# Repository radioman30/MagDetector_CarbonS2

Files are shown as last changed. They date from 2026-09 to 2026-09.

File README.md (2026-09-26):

# MagDetector — Carbon S2

Instrument portabil 4-în-1 pe GroundStudio Carbon S2 (ESP32-S2FN4R2):
**busolă** · **detector poli magnet** · **detector cabluri 50 Hz** · **mini stație meteo**

## Hardware

| Componentă | Conexiune |
|---|---|
| HMC5883L (magnetometru, original Honeywell, 0x1E) | I2C: SDA=GPIO8, SCL=GPIO9 |
| BME280 (temp/umiditate/presiune, 0x77) | același I2C |
| TFT ST7735 1.8" 128×160 | SCK=36, MOSI=35, CS=37, DC=38, RST=33, BLK=14 |
| Buton moduri | BOOT (GPIO0) **sau** buton extern GPIO4→GND |
| Buzzer pasiv | GPIO5→GND |
| Baterie LiPo 1S | conectorul plăcii; măsurare internă pe GPIO3, VBUS pe GPIO21 |

**Atenție GPIO3**: e nod triplu (divizor 442k/160k + pinul CHRG al charger-ului
BRCL4054 + LED-ul de charging). Tensiunea bateriei e validă **doar fără USB**;
la încărcare pinul e tras la ~0V (firmware-ul afișează "se incarca").
`BAT_DIV = 3.790` calibrat cu multimetrul (teoretic 3.7625).

## Utilizare

- **Apăsare scurtă** buton = următorul mod (beep cu ton diferit per mod)
- **Apăsare lungă (1.5s) în modul Busolă** = calibrare hard-iron: rotește în 8
  pe toate axele 20s; se salvează în NVS, se face o singură dată
- **Cabluri**: funcționează doar pe cabluri prin care TRECE CURENT — pornește
  un consumator mare (aerotermă 2kW) pe circuit. Detecție prin filtru Goertzel
  pe 50 Hz (aliazat la 25 Hz, fs=75 Hz, N=96), prag 0.15 µT
- **Magnet**: polaritate pe axa Z (semn inversat, verificat cu busolă reală);
  la "SATURAT" depărtează magnetul

## Compilare & upload

```
arduino-cli (din C:\Users\123\ArduinoCompiler\arduino-cli\)
FQBN: esp32:esp32:esp32s2:CDCOnBoot=cdc,FlashSize=4M,PSRAM=enabled
```

Portul COM se re-enumerează la fiecare reset (COM24–27...) — refă
`arduino-cli board list` înainte de upload; de obicei merge din a 2-a încercare.
Biblioteci: Adafruit GFX + ST7735 + BME280 (instalate).

## Structură

- `MagDetector/` — firmware-ul principal (v1.1, cu Goertzel pe modul cabluri)
- `I2C_Scan/` — scanner I2C cu autodetecție pini și identificare chip-uri
- `carcasa/` — carcasă parametrică OpenSCAD + STL-uri gata de print:
  - `magdetector_baza.stl`, `magdetector_capac.stl` (46×152×26 mm)
  - PLA/PETG, 0.2 mm, 3 perimetre, fără suporturi, ambele piese flat pe pat
  - cioc-sondă în față pt. GY-271 (departe de electronică!), fereastră TFT,
    buton pe capac, USB-C lateral dreapta, compartiment LiPo 36×54×10
  - de verificat înainte de print: găurile modulului de display la
    29.5×51.5 mm (`disp_hole_dx/dy`), dimensiunea bateriei (`bat_bay`)
  - asamblare: 4×M3×20-25 prin podea + 4×M2×5 pt display

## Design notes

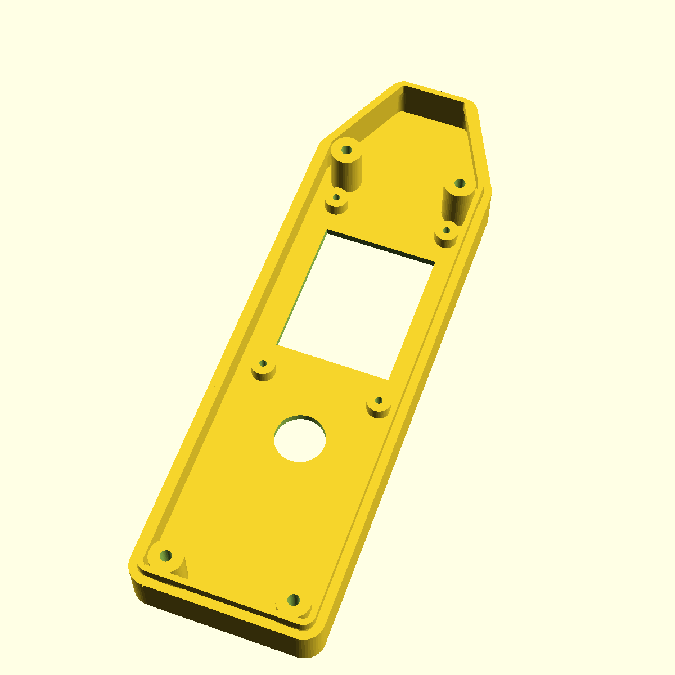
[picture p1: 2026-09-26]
carcasa/preview_lid.png

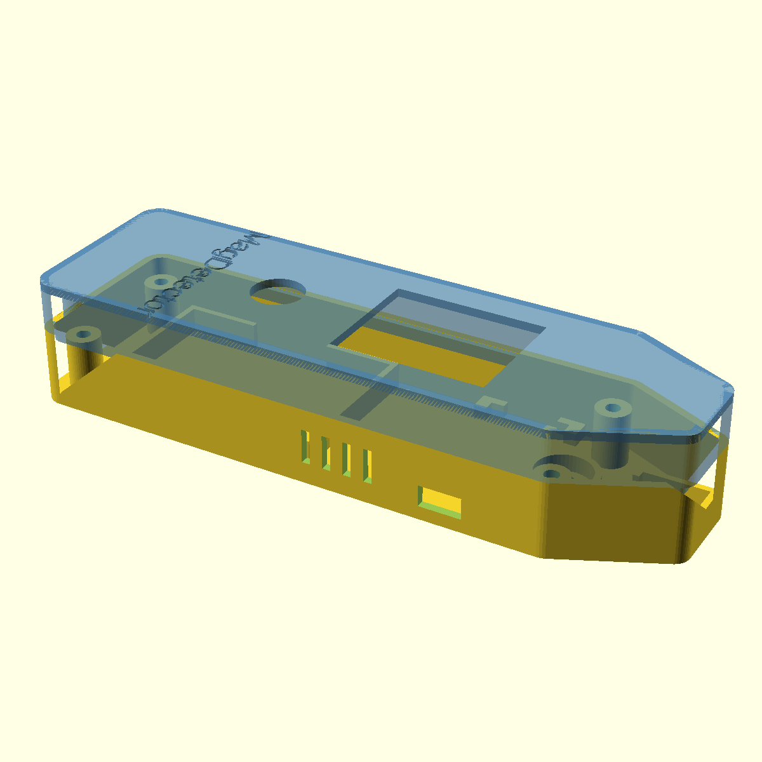
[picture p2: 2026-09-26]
carcasa/preview_final.png

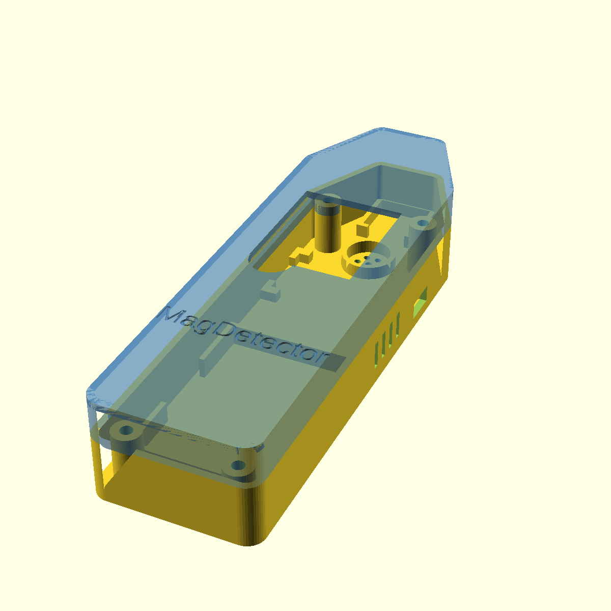
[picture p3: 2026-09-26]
carcasa/preview_all.png

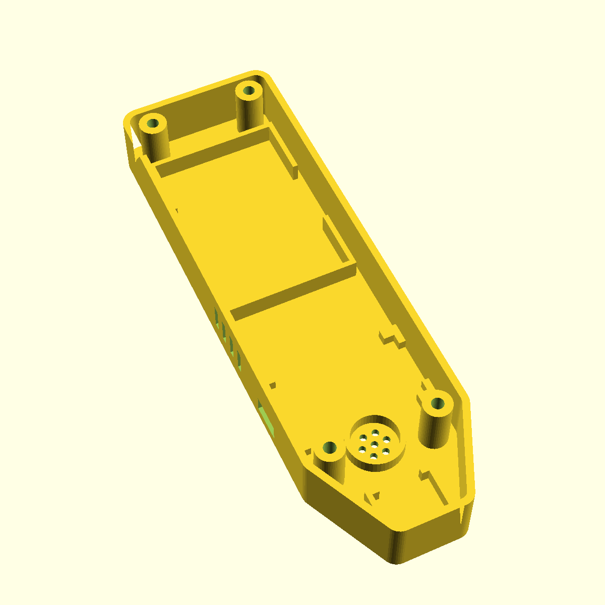
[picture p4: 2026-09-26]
carcasa/preview_base.png

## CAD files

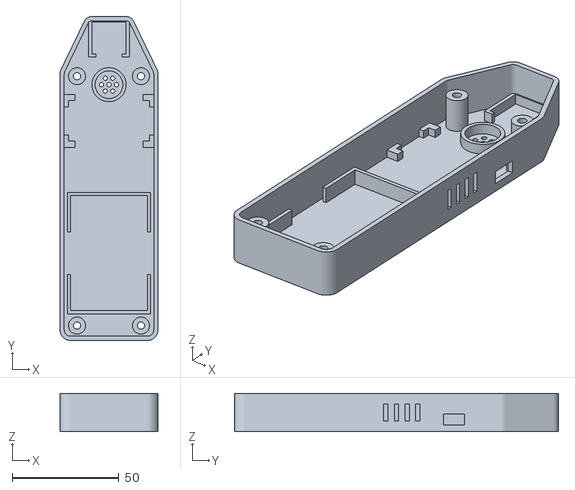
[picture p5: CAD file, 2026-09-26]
carcasa/magdetector_baza.stl
46.0 x 152.0 x 18.0

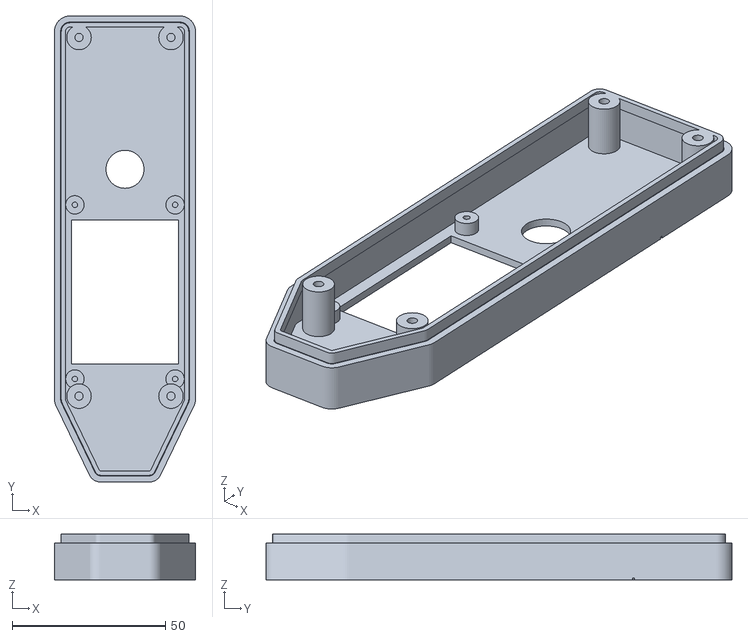
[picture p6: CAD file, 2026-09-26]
carcasa/magdetector_capac.stl
46.0 x 152.0 x 15.0

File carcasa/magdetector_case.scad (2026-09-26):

// ============================================================
//  Carcasa MagDetector - Carbon S2 + ST7735 1.8" + GY-271 + BME280
//  Doua piese: baza (tava) si capac (cu fereastra display + buton)
//  Sonda magnetometru in "ciocul" din fata, departe de electronica.
//
//  Randare: part = "base" | "lid" | "all" (previzualizare asamblata)
//  Toate cotele sunt parametrice - ajusteaza si regenereaza.
// ============================================================

part = "all";

$fn = 48;

/* ---------------- Parametri generali ---------------- */
wall      = 2.0;    // grosime pereti
floor_t   = 2.0;    // grosime podea / placa capac
body_w    = 46;     // latime exterioara corp
body_l    = 130;    // lungime exterioara corp
corner_r  = 5;      // raza colturi corp
nose_w    = 24;     // latime cioc sonda
nose_l    = 22;     // lungime cioc (dincolo de corp)
nose_r    = 4;      // raza colturi cioc
base_h    = 18;     // inaltime exterioara baza
lid_h     = 12;     // inaltime exterioara capac
lip_h     = 3;      // buza de imbinare capac->baza
clr       = 0.20;   // joc de imbinare

/* ---------------- Display ST7735 1.8" ---------------- */
disp_cy      = 90;     // centrul modulului pe axa Y
disp_hole_dx = 32.7;   // distanta gauri montaj pe X (masurat centru-centru)
disp_hole_dy = 56.8;   // distanta gauri montaj pe Y (masurat centru-centru)
disp_boss_d  = 6;      // diametru bosaje
disp_boss_h  = 3.5;    // inaltime bosaje (aduce sticla la fata)
disp_pilot   = 1.8;    // pilot M2 autofiletant
win_w        = 35;     // fereastra (sticla 34.5 + 0.5 joc)
win_l        = 47;     // fereastra (sticla 46.5 + 0.5 joc)
win_off_y    = 0;      // ajustare fina fereastra fata de centru modul

/* ---------------- Buton / buzzer / senzori ---------------- */
btn_pos   = [0, 50];   // centrul gaurii de buton pe capac (sub display, deasupra bateriei)
btn_d     = 12.4;      // gaura buton panou 12mm
buz_pos   = [0, 120];  // buzzer pe podea baza
buz_d     = 13;        // diametru locas buzzer (disc 12mm)
bme_vent_y = [70, 86]; // zona fantelor de aerisire BME280 (perete dreapta)
usb_cy    = 103;       // centrul decupajului USB-C (perete dreapta)
usb_w     = 10;        // latime decupaj USB
usb_h     = 5;         // inaltime decupaj USB
gy_pock   = [16, 15];  // buzunar GY-271 in cioc (X x Y)

/* ---------------- Baterie LiPo ---------------- */
bat_bay   = [36, 54];  // compartiment baterie (X x Y)
bat_y0    = 14;        // inceputul compartimentului pe Y
bay_wall  = 1.5;
bay_h     = 6;

/* ---------------- Suruburi carcasa (M3) ---------------- */
post_d    = 8;
post_pos  = [[-15, 7], [15, 7], [-15, 124], [15, 124]];
screw_thru = 3.4;      // gaura libera M3 in baza
screw_pilot = 2.7;     // pilot M3 in capac
csink_d   = 6.5;       // cap surub ingropat

/* ---------------- Carbon S2 ---------------- */
pcb_l = 37.5;          // lungime placa (transversal, USB spre dreapta)
pcb_w = 18.5;
pcb_cy = disp_cy + 13; // sub jumatatea de sus a display-ului

// ============================================================
//  Conturul carcasei (corp + cioc, unite prin hull -> taper)
// ============================================================
module case_outline(o = 0) {
  offset(r = o) hull() {
    offset(r = corner_r) offset(delta = -corner_r)
      translate([-body_w/2, 0]) square([body_w, body_l]);
    offset(r = nose_r) offset(delta = -nose_r)
      translate([-nose_w/2, body_l - 1]) square([nose_w, nose_l + 1]);
  }
}

// ============================================================
//  BAZA
// ============================================================
module base() {
  difference() {
    union() {
      // podea
      linear_extrude(floor_t) case_outline();
      // pereti
      linear_extrude(base_h)
        difference() { case_outline(); case_outline(-wall); }

      // compartiment baterie
      translate([0, bat_y0 + bat_bay[1]/2, 0]) linear_extrude(floor_t + bay_h)
        difference() {
          square([bat_bay[0] + 2*bay_wall, bat_bay[1] + 2*bay_wall], center = true);
          square([bat_bay[0], bat_bay[1]], center = true);
          // ferestre laterale pt banda velcro / degete
          square([bat_bay[0] + 4*bay_wall, 20], center = true);
        }

      // ghidaje colturi Carbon S2 (placa transversala, USB spre dreapta)
      for (sx = [-1, 1], sy = [-1, 1])
        translate([sx*(pcb_l/2 + 0.25), pcb_cy + sy*(pcb_w/2 + 0.25), floor_t])
          linear_extrude(3) difference() {
            square([6, 6], center = true);
            translate([-sx*3, -sy*3]) square([6, 6], center = true);
          }

      // inel locas buzzer
      translate([buz_pos[0], buz_pos[1], 0]) linear_extrude(floor_t + 4)
        difference() { circle(d = buz_d + 3); circle(d = buz_d); }

      // buzunar GY-271 in cioc (3 pereti, deschis spre corp pt fire)
      translate([0, body_l + nose_l/2 + 1, floor_t]) linear_extrude(4)
        difference() {
          square([gy_pock[0] + 3, gy_pock[1] + 3], center = true);
          square([gy_pock[0], gy_pock[1]], center = true);
          translate([0, -gy_pock[1]/2 - 3]) square([gy_pock[0] - 4, 8], center = true);
        }

      // coloane suruburi (se opresc sub buza capacului)
      for (p = post_pos)
        translate([p[0], p[1], 0]) cylinder(d = post_d, h = base_h - lip_h - 0.2);
    }

    // gauri suruburi + cap ingropat
    for (p = post_pos) translate([p[0], p[1], -0.01]) {
      cylinder(d = screw_thru, h = base_h + 1);
      cylinder(d = csink_d, h = 1.8);
    }

    // decupaj USB-C, perete dreapta
    translate([body_w/2 - wall - 0.5, usb_cy - usb_w/2, floor_t + 1.2])
      cube([wall + 1.5, usb_w, usb_h]);

    // fante aerisire BME280, perete dreapta
    for (y = [bme_vent_y[0] : 5 : bme_vent_y[1]])
      translate([body_w/2 - wall - 0.5, y, floor_t + 3])
        cube([wall + 1.5, 2, 8]);

    // gauri sunet buzzer, in podea
    translate([buz_pos[0], buz_pos[1], -0.01]) {
      cylinder(d = 2, h = floor_t + 1);
      for (a = [0:60:300]) rotate([0, 0, a])
        translate([3.5, 0, 0]) cylinder(d = 2, h = floor_t + 1);
    }
  }
}

// ============================================================
//  CAPAC (modelat in orientarea asamblata; z=0 la marginea de jos)
// ============================================================
module lid() {
  difference() {
    union() {
      // placa superioara
      translate([0, 0, lid_h - floor_t]) linear_extrude(floor_t) case_outline();
      // fusta
      linear_extrude(lid_h)
        difference() { case_outline(); case_outline(-wall); }
      // buza care intra in baza
      translate([0, 0, -lip_h]) linear_extrude(lip_h + 0.01)
        difference() { case_outline(-wall - clr); case_outline(-wall - clr - 1.4); }

      // bosaje montaj display (M2)
      for (sx = [-1, 1], sy = [-1, 1])
        translate([sx*disp_hole_dx/2, disp_cy + sy*disp_hole_dy/2, lid_h - floor_t - disp_boss_h])
          cylinder(d = disp_boss_d, h = disp_boss_h);

      // coloane primire suruburi M3
      for (p = post_pos)
        translate([p[0], p[1], -lip_h])
          cylinder(d = post_d, h = lid_h - floor_t + lip_h);
    }

    // fereastra display
    translate([0, disp_cy + win_off_y, lid_h - floor_t - 0.5])
      linear_extrude(floor_t + 1)
        square([win_w, win_l], center = true);

    // gaura buton
    translate([btn_pos[0], btn_pos[1], lid_h - floor_t - 0.5])
      cylinder(d = btn_d, h = floor_t + 1);

    // piloti M2 display
    for (sx = [-1, 1], sy = [-1, 1])
      translate([sx*disp_hole_dx/2, disp_cy + sy*disp_hole_dy/2, lid_h - floor_t - disp_boss_h - 0.5])
        cylinder(d = disp_pilot, h = disp_boss_h + 0.4);

    // piloti M3 capac
    for (p = post_pos)
      translate([p[0], p[1], -lip_h - 0.01])
        cylinder(d = screw_pilot, h = 9);

    // text gravat
    translate([0, 30, lid_h - 0.6])
      linear_extrude(1)
        text("MagDetector", size = 6, halign = "center", valign = "center");
  }
}

// ============================================================
//  Selectie piesa
// ============================================================
if (part == "base") base();
if (part == "lid")  rotate([180, 0, 0]) translate([0, 0, -lid_h]) lid();  // rasturnat pt printare
if (part == "all") {
  base();
  color("SteelBlue", 0.65) translate([0, 0, base_h]) lid();
}

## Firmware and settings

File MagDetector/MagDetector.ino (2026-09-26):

// ============================================================
//  MagDetector - GroundStudio Carbon S2 (ESP32-S2FN4R2)
//  4 moduri, comutate cu butonul BOOT (GPIO0):
//    1. Busola      - HMC5883L, heading cu calibrare hard-iron
//    2. Poli magnet - N/S + intensitate camp (gain redus)
//    3. Cabluri AC  - detectie camp 50 Hz (varianta pe axe)
//    4. Meteo       - BME280: temperatura, umiditate, presiune
//  Apasare lunga (>1.5s) in modul Busola = calibrare (roteste in 8)
//
//  Hardware:
//    I2C  SDA=GPIO8 SCL=GPIO9  -> HMC5883L (0x1E) + BME280 (0x77)
//    TFT ST7735 1.8" 128x160   -> SCK=36 MOSI=35 CS=37 DC=38 RST=33 BLK=14
//    Buton = BOOT (GPIO0), Buzzer optional = GPIO5
// ============================================================

#include <Wire.h>
#include <SPI.h>
#include <Adafruit_GFX.h>
#include <Adafruit_ST7735.h>
#include <Adafruit_BME280.h>
#include <Preferences.h>

// ---------------- Pini ----------------
#define PIN_SDA       8
#define PIN_SCL       9
#define PIN_TFT_SCK   36
#define PIN_TFT_MOSI  35
#define PIN_TFT_CS    37
#define PIN_TFT_DC    38
#define PIN_TFT_RST   33
#define PIN_TFT_BLK   14
#define PIN_BTN       0     // butonul BOOT de pe placa
#define PIN_BTN_EXT   4     // buton extern la GND (pull-up intern)
#define PIN_BUZZER    5     // buzzer pasiv la GND
// GPIO3 e nod triplu pe Carbon S2 (confirmat din PCB REV0.0.2):
//  - divizor 442k/160k spre +BAT (citire tensiune)
//  - pinul CHRG/STAT al charger-ului BRCL4054: tras la ~0V cat timp incarca
//  - LED-ul verde de charging (alimentat din USB_VCC prin 20k, jumper J2)
// => tensiunea e valida DOAR pe baterie (fara USB); pe USB afisam doar starea
#define PIN_BAT_ADC   3
#define PIN_VBUS      21      // HIGH = alimentare 5V pe USB prezenta
#define BAT_DIV       3.790f  // teoretic 3.7625 (602k/160k), calibrat cu multimetrul: 3.445V real / 3.42V afisat

// Varianta de tab a display-ului: daca imaginea e deplasata sau culorile
// sunt ciudate, incearca INITR_GREENTAB sau INITR_REDTAB
#define TAB_VARIANT   INITR_BLACKTAB

// Declinatia magnetica pentru Romania (~6.3 grade Est, 2026)
#define DECLINATIE_DEG 6.3f

// Inclinatia magnetica pentru Romania (~63 grade - campul "intra" in pamant).
// Referinta pentru bula de nivel; ajusteaza +/- cateva grade daca bula
// nu sta centrata cand aparatul e perfect orizontal (offset de montaj senzor).
#define DIP_REF_DEG 63.0f

// ---------------- HMC5883L ----------------
#define HMC_ADDR      0x1E
#define HMC_REG_CRA   0x00
#define HMC_REG_CRB   0x01
#define HMC_REG_MODE  0x02
#define HMC_REG_DATA  0x03
#define HMC_REG_STAT  0x09

// uT per LSB pentru cele doua gain-uri folosite
#define UT_PER_LSB_1_3GA (100.0f / 1090.0f)  // gain 1.3 Ga (busola, cabluri)
#define UT_PER_LSB_8_1GA (100.0f / 230.0f)   // gain 8.1 Ga (magneti)

Adafruit_ST7735 tft(PIN_TFT_CS, PIN_TFT_DC, PIN_TFT_RST);
Adafruit_BME280 bme;
Preferences prefs;
bool bmeOk = false;

// ---------------- Moduri ----------------
enum Mode { MODE_BUSOLA = 0, MODE_MAGNET, MODE_CABLU, MODE_METEO, NUM_MODES };
Mode mode = MODE_BUSOLA;

// Calibrare hard-iron (offset) + soft-iron simplu (scala)
float offX = 0, offY = 0, offZ = 0;
float sclX = 1, sclY = 1, sclZ = 1;

// Filtru exponential pt busola
float fX = 0, fY = 0, fZ = 0;
bool  fInit = false;
int   lastNeedleAngle = -999;

// Buffer circular pt detectia AC (modul cabluri)
// N=96 la fs=75Hz: 50Hz aliazeaza pe 25Hz = exact bin-ul k=32 al ferestrei
// (si armonica de 100Hz aliazeaza tot pe 25Hz - se cumuleaza, ne ajuta)
#define AC_N 96
float acX[AC_N], acY[AC_N], acZ[AC_N];
int   acIdx = 0, acCount = 0;
#define HIST_N 128
uint8_t hist[HIST_N];
int histIdx = 0;

// Buton
bool     btnWasDown = false;
uint32_t btnDownAt = 0;
bool     longFired = false;

uint32_t tSample = 0, tUi = 0, tBat = 0;
float curUtPerLsb = UT_PER_LSB_1_3GA;

// ---------------- Driver HMC5883L ----------------
void hmcWrite(uint8_t reg, uint8_t val) {
  Wire.beginTransmission(HMC_ADDR);
  Wire.write(reg);
  Wire.write(val);
  Wire.endTransmission();
}

// cra: averaging+rata, crb: gain. Porneste modul continuu.
void hmcConfig(uint8_t cra, uint8_t crb) {
  hmcWrite(HMC_REG_CRA, cra);
  hmcWrite(HMC_REG_CRB, crb);
  hmcWrite(HMC_REG_MODE, 0x00);  // continuu
  curUtPerLsb = ((crb >> 5) == 0b111) ? UT_PER_LSB_8_1GA : UT_PER_LSB_1_3GA;
  delay(10);
}

bool hmcDataReady() {
  Wire.beginTransmission(HMC_ADDR);
  Wire.write(HMC_REG_STAT);
  if (Wire.endTransmission(false) != 0) return false;
  if (Wire.requestFrom(HMC_ADDR, 1) != 1) return false;
  return Wire.read() & 0x01;
}

// Ordinea registrelor HMC5883L este X, Z, Y (big endian)!
bool hmcRead(int16_t &x, int16_t &y, int16_t &z) {
  Wire.beginTransmission(HMC_ADDR);
  Wire.write(HMC_REG_DATA);
  if (Wire.endTransmission(false) != 0) return false;
  if (Wire.requestFrom(HMC_ADDR, 6) != 6) return false;
  x = (Wire.read() << 8) | Wire.read();
  z = (Wire.read() << 8) | Wire.read();
  y = (Wire.read() << 8) | Wire.read();
  return true;
}

bool hmcSaturated(int16_t x, int16_t y, int16_t z) {
  return x == -4096 || y == -4096 || z == -4096;
}

// ---------------- UI comun ----------------
const uint16_t modeColor[NUM_MODES] = {ST77XX_BLUE, ST77XX_RED, ST77XX_ORANGE, 0x0560};
const char* modeName[NUM_MODES] = {"BUSOLA", "MAGNET", "CABLURI", "METEO"};

float readBatV() {
  uint32_t mv = 0;
  for (int i = 0; i < 8; i++) mv += analogReadMilliVolts(PIN_BAT_ADC);
  return (mv / 8) * BAT_DIV / 1000.0f;
}

// curba de descarcare LiPo 1S, aproximata pe segmente
int batPercent(float v) {
  const float vp[] = {3.30, 3.50, 3.70, 3.80, 3.95, 4.15};
  const int   pp[] = {0,    10,   25,   50,   75,   100};
  if (v <= vp[0]) return 0;
  if (v >= vp[5]) return 100;
  for (int i = 5; i > 0; i--)
    if (v >= vp[i - 1])
      return pp[i - 1] + (v - vp[i - 1]) * (pp[i] - pp[i - 1]) / (vp[i] - vp[i - 1]);
  return 0;
}

void drawBattery() {
  float v = readBatV();
  tft.fillRect(62, 0, 66, 16, modeColor[mode]);
  tft.setTextSize(1);
  tft.setTextColor(ST77XX_WHITE);
  tft.setCursor(66, 4);
  if (digitalRead(PIN_VBUS)) {
    // pe USB: STAT jos = incarcare; sus = plin (citirea e alterata de LED)
    tft.print(v < 1.0f ? "se incarca" : "USB: plin");
  } else {
    tft.printf("%.2fV %d%%", v, batPercent(v));
  }
}

void drawHeader() {
  tft.fillRect(0, 0, 128, 16, modeColor[mode]);
  tft.setTextColor(ST77XX_WHITE);
  tft.setTextSize(1);
  tft.setCursor(4, 4);
  tft.print(modeName[mode]);
  drawBattery();
}

void drawFooter(const char* msg) {
  tft.fillRect(0, 150, 128, 10, ST77XX_BLACK);
  tft.setTextSize(1);
  tft.setTextColor(0x7BEF);  // gri
  tft.setCursor(2, 151);
  tft.print(msg);
}

// ---------------- Busola ----------------
// Literele sunt separate ca sa le putem redesena dupa stergerea acului
// (varful acului trece peste ele si le "manca")
void drawCompassLabels() {
  const int cx = 64, cy = 78, R = 50;
  tft.setTextSize(1);
  tft.setTextColor(ST77XX_RED);   tft.setCursor(cx - 2, cy - R + 5);  tft.print("N");
  tft.setTextColor(ST77XX_WHITE); tft.setCursor(cx + R - 12, cy - 3); tft.print("E");
  tft.setCursor(cx - 2, cy + R - 11); tft.print("S");
  tft.setCursor(cx - R + 7, cy - 3);  tft.print("V");
}

void drawCompassFace() {
  const int cx = 64, cy = 78, R = 50;
  tft.drawCircle(cx, cy, R, ST77XX_WHITE);
  tft.drawCircle(cx, cy, R + 1, ST77XX_WHITE);
  for (int a = 0; a < 360; a += 30) {
    float r = radians(a);
    int x1 = cx + (R - 4) * sinf(r), y1 = cy - (R - 4) * cosf(r);
    int x2 = cx + (R - 1) * sinf(r), y2 = cy - (R - 1) * cosf(r);
    tft.drawLine(x1, y1, x2, y2, ST77XX_WHITE);
  }
  drawCompassLabels();
}

// Bula de nivel "magnetica": compara inclinatia masurata a campului terestru
// cu cea de referinta (63 grade). Fara accelerometru detecteaza bine
// inclinarea in planul nord-sud si slab pe cea laterala (est-vest).
void drawBubble(float devDeg) {
  const int bx = 2, by = 19, bw = 34, bh = 11;
  tft.fillRect(bx, by, bw, bh, ST77XX_BLACK);
  tft.drawRoundRect(bx, by, bw, bh, 4, 0x7BEF);
  // reperele centrale ale nivelei
  tft.drawFastVLine(bx + bw / 2 - 4, by + 2, bh - 4, 0x39E7);
  tft.drawFastVLine(bx + bw / 2 + 4, by + 2, bh - 4, 0x39E7);
  bool ok = fabsf(devDeg) < 3.0f;                       // "drept" = sub 3 grade
  int dx = (int)constrain(devDeg * 1.5f, -11.0f, 11.0f); // 1.5 px / grad
  tft.fillCircle(bx + bw / 2 + dx, by + bh / 2, 3, ok ? ST77XX_GREEN : ST77XX_YELLOW);
}

void drawNeedle(int angleDeg, bool erase) {
  const int cx = 64, cy = 78, L = 40;
  float r = radians((float)angleDeg);
  int nx = cx + L * sinf(r), ny = cy - L * cosf(r);
  int tx = cx - (L / 2) * sinf(r), ty = cy + (L / 2) * cosf(r);
  uint16_t cN = erase ? ST77XX_BLACK : ST77XX_RED;
  uint16_t cS = erase ? ST77XX_BLACK : 0x7BEF;
  tft.drawLine(cx, cy, nx, ny, cN);
  tft.drawLine(cx + 1, cy, nx + 1, ny, cN);
  tft.drawLine(cx, cy, tx, ty, cS);
  if (!erase) tft.fillCircle(cx, cy, 3, ST77XX_WHITE);
}

const char* cardinal(float h) {
  static const char* dir[] = {"N", "NE", "E", "SE", "S", "SV", "V", "NV"};
  return dir[((int)((h + 22.5f) / 45.0f)) % 8];
}

int lastBubbleX = -999;

void uiBusola(float mx, float my, float mz) {
  // filtrare vectoriala ca sa nu tremure acul
  if (!fInit) { fX = mx; fY = my; fZ = mz; fInit = true; }
  fX += 0.25f * (mx - fX);
  fY += 0.25f * (my - fY);
  fZ += 0.25f * (mz - fZ);

  float heading = degrees(atan2f(fY, fX)) + DECLINATIE_DEG;
  if (heading < 0) heading += 360;
  if (heading >= 360) heading -= 360;

  // acul arata Nordul pe cadran (rotit invers fata de heading)
  int needle = (int)(360 - heading) % 360;
  if (needle != lastNeedleAngle) {
    if (lastNeedleAngle > -999) drawNeedle(lastNeedleAngle, true);
    drawCompassLabels();  // stergerea acului trece peste litere - le refacem
    drawNeedle(needle, false);
    lastNeedleAngle = needle;
  }

  // bula: deviatia inclinatiei magnetice fata de referinta
  float dip = degrees(atan2f(fabsf(fZ), sqrtf(fX * fX + fY * fY)));
  int bubX = (int)constrain((dip - DIP_REF_DEG) * 1.5f, -11.0f, 11.0f);
  if (bubX != lastBubbleX) {  // redesenam doar cand se misca, sa nu clipeasca
    drawBubble(dip - DIP_REF_DEG);
    lastBubbleX = bubX;
  }

  tft.fillRect(0, 132, 128, 16, ST77XX_BLACK);
  tft.setTextSize(2);
  tft.setTextColor(ST77XX_YELLOW);
  tft.setCursor(22, 132);
  tft.printf("%3.0f%c %s", heading, 247, cardinal(heading));
}

// ---------------- Poli magnet ----------------
char lastPole = '?';
void uiMagnet(int16_t rx, int16_t ry, int16_t rz, bool sat) {
  float bx = rx * curUtPerLsb, by = ry * curUtPerLsb, bz = rz * curUtPerLsb;
  float mag = sqrtf(bx * bx + by * by + bz * bz);

  tft.fillRect(0, 20, 128, 128, ST77XX_BLACK);
  tft.setTextSize(1);

  if (sat) {
    tft.setTextSize(3);
    tft.setTextColor(ST77XX_MAGENTA);
    tft.setCursor(10, 55);
    tft.print("SATURAT");
    tft.setTextSize(1);
    tft.setTextColor(ST77XX_WHITE);
    tft.setCursor(14, 90);
    tft.print("departeaza magnetul");
    return;
  }

  if (mag < 150) {  // doar campul terestru -> niciun magnet aproape
    tft.setTextColor(ST77XX_WHITE);
    tft.setCursor(16, 60);
    tft.print("Apropie un magnet");
    tft.setCursor(24, 100);
    tft.printf("camp: %.1f uT", mag);
    lastPole = '?';
    return;
  }

  // polaritatea dupa axa dominanta (Z = fata senzorului)
  // semn inversat: verificat cu busola pe modulul real
  bool north = bz < 0;
  tft.setTextSize(7);
  tft.setTextColor(north ? ST77XX_RED : ST77XX_BLUE);
  tft.setCursor(44, 40);
  tft.print(north ? "N" : "S");
  tft.setTextSize(1);
  tft.setTextColor(ST77XX_WHITE);
  tft.setCursor(north ? 34 : 40, 96);
  tft.print(north ? "polul NORD" : "polul SUD");

  // bargraph intensitate (log, 150..2500 uT)
  float frac = constrain((log10f(mag) - log10f(150)) / (log10f(2500) - log10f(150)), 0.0f, 1.0f);
  tft.drawRect(9, 112, 110, 12, ST77XX_WHITE);
  tft.fillRect(11, 114, (int)(106 * frac), 8, north ? ST77XX_RED : ST77XX_BLUE);
  tft.setCursor(34, 130);
  tft.printf("%.0f uT", mag);
}

// ---------------- Cabluri AC ----------------
// Amplitudinea componentei de 25 Hz (= 50 Hz aliazat) prin filtru Goertzel.
// N=96, k=32 -> coeff = 2*cos(2*pi*32/96) = -1, deci recurenta e triviala.
float goertzel50Hz(float* buf, int startIdx) {
  float mean = 0;
  for (int i = 0; i < AC_N; i++) mean += buf[(startIdx + i) % AC_N];
  mean /= AC_N;
  float s1 = 0, s2 = 0;
  for (int i = 0; i < AC_N; i++) {
    float s = (buf[(startIdx + i) % AC_N] - mean) - s1 - s2;
    s2 = s1;
    s1 = s;
  }
  float power = s1 * s1 + s2 * s2 + s1 * s2;
  return 2.0f * sqrtf(max(power, 0.0f)) / AC_N;  // amplitudine varf, uT
}

void uiCablu() {
  if (acCount < AC_N) return;  // asteapta umplerea ferestrei
  float gx = goertzel50Hz(acX, acIdx);
  float gy = goertzel50Hz(acY, acIdx);
  float gz = goertzel50Hz(acZ, acIdx);
  float level = sqrtf(gx * gx + gy * gy + gz * gz);  // amplitudine vectoriala 50Hz

  // istoric scalat logaritmic: 0.02 .. 10 uT -> 0..40 px
  float frac = constrain((log10f(max(level, 0.005f)) - log10f(0.02f)) /
                         (log10f(10.0f) - log10f(0.02f)), 0.0f, 1.0f);
  hist[histIdx] = (uint8_t)(frac * 40);
  histIdx = (histIdx + 1) % HIST_N;

  tft.fillRect(0, 20, 128, 50, ST77XX_BLACK);
  tft.setTextSize(3);
  bool detect = level > 0.15f;
  tft.setTextColor(detect ? ST77XX_GREEN : ST77XX_WHITE);
  tft.setCursor(10, 28);
  if (level < 10) tft.printf("%.2f", level);
  else            tft.printf("%.1f", level);
  tft.setTextSize(1);
  tft.setTextColor(0x7BEF);
  tft.setCursor(92, 42);
  tft.print("uT AC");

  tft.fillRect(0, 60, 128, 10, ST77XX_BLACK);
  tft.setCursor(2, 60);
  tft.setTextColor(detect ? ST77XX_GREEN : 0x7BEF);
  // max 21 caractere pe linie (128px / 6px per caracter)
  tft.print(detect ? ">> CAMP 50Hz DETECTAT" : "cauta...consumator ON");

  // grafic istoric
  tft.fillRect(0, 74, 128, 42, 0x1082);
  for (int i = 0; i < HIST_N; i++) {
    int v = hist[(histIdx + i) % HIST_N];
    if (v > 0) tft.drawFastVLine(i, 115 - v, v, ST77XX_ORANGE);
  }
  tft.drawFastHLine(0, 115, 128, ST77XX_WHITE);

  tft.fillRect(0, 120, 128, 26, ST77XX_BLACK);
  tft.setCursor(2, 122);
  tft.setTextColor(0x7BEF);
  tft.printf("X:%.2f Y:%.2f Z:%.2f", gx, gy, gz);

  if (detect) tone(PIN_BUZZER, 300 + (int)(frac * 1200), 80);
}

// ---------------- Meteo ----------------
void uiMeteo() {
  tft.fillRect(0, 20, 128, 128, ST77XX_BLACK);
  if (!bmeOk) {
    tft.setTextSize(1);
    tft.setTextColor(ST77XX_RED);
    tft.setCursor(14, 70);
    tft.print("BME280 negasit!");
    return;
  }
  float t = bme.readTemperature();
  float h = bme.readHumidity();
  float p = bme.readPressure() / 100.0f;
  // punct de roua (aproximatia Magnus)
  float g = logf(h / 100.0f) + 17.62f * t / (243.12f + t);
  float dew = 243.12f * g / (17.62f - g);

  tft.setTextSize(3);
  tft.setTextColor(ST77XX_YELLOW);
  tft.setCursor(14, 28);
  tft.printf("%.1f%cC", t, 247);

  tft.setTextSize(2);
  tft.setTextColor(ST77XX_CYAN);
  tft.setCursor(14, 62);
  tft.printf("%.0f %%RH", h);

  tft.setTextColor(ST77XX_GREEN);
  tft.setCursor(14, 88);
  tft.printf("%.1f", p);
  tft.setTextSize(1);
  tft.setCursor(98, 95);
  tft.print("hPa");

  tft.setTextColor(0x7BEF);
  tft.setCursor(14, 118);
  tft.printf("punct roua: %.1f%cC", dew, 247);
}

// ---------------- Calibrare busola ----------------
void runCalibration() {
  tft.fillScreen(ST77XX_BLACK);
  tft.setTextSize(1);
  tft.setTextColor(ST77XX_YELLOW);
  tft.setCursor(10, 30);  tft.print("CALIBRARE BUSOLA");
  tft.setTextColor(ST77XX_WHITE);
  tft.setCursor(10, 50);  tft.print("Roteste placa in 8,");
  tft.setCursor(10, 62);  tft.print("pe toate axele, 20s");

  hmcConfig(0x18, 0x20);  // 75 Hz, gain 1.3 Ga
  float xmin = 1e9, xmax = -1e9, ymin = 1e9, ymax = -1e9, zmin = 1e9, zmax = -1e9;
  uint32_t t0 = millis();
  while (millis() - t0 < 20000) {
    if (hmcDataReady()) {
      int16_t x, y, z;
      if (hmcRead(x, y, z) && !hmcSaturated(x, y, z)) {
        xmin = min(xmin, (float)x); xmax = max(xmax, (float)x);
        ymin = min(ymin, (float)y); ymax = max(ymax, (float)y);
        zmin = min(zmin, (float)z); zmax = max(zmax, (float)z);
      }
    }
    int w = (millis() - t0) * 108 / 20000;
    tft.drawRect(9, 90, 110, 10, ST77XX_WHITE);
    tft.fillRect(10, 91, w, 8, ST77XX_GREEN);
    delay(5);
  }

  offX = (xmin + xmax) / 2; offY = (ymin + ymax) / 2; offZ = (zmin + zmax) / 2;
  float rx = max((xmax - xmin) / 2, 1.0f);
  float ry = max((ymax - ymin) / 2, 1.0f);
  float rz = max((zmax - zmin) / 2, 1.0f);
  float ravg = (rx + ry + rz) / 3;
  sclX = ravg / rx; sclY = ravg / ry; sclZ = ravg / rz;

  prefs.putFloat("offX", offX); prefs.putFloat("offY", offY); prefs.putFloat("offZ", offZ);
  prefs.putFloat("sclX", sclX); prefs.putFloat("sclY", sclY); prefs.putFloat("sclZ", sclZ);

  tft.setTextColor(ST77XX_GREEN);
  tft.setCursor(38, 112);
  tft.print("SALVAT!");
  delay(1200);
  fInit = false;
  enterMode();
}

// ---------------- Comutare moduri ----------------
void enterMode() {
  noTone(PIN_BUZZER);
  tft.fillScreen(ST77XX_BLACK);
  drawHeader();
  lastNeedleAngle = -999;
  lastBubbleX = -999;
  fInit = false;
  acIdx = acCount = 0;

  switch (mode) {
    case MODE_BUSOLA:
      hmcConfig(0x70, 0x20);  // 8 medieri, 15 Hz, 1.3 Ga - stabil
      drawCompassFace();
      drawFooter("BOOT=mod  lung=calibrare");
      break;
    case MODE_MAGNET:
      hmcConfig(0x18, 0xE0);  // 75 Hz, gain 8.1 Ga - camp mare
      drawFooter("BOOT=mod urmator");
      break;
    case MODE_CABLU:
      hmcConfig(0x18, 0x20);  // 75 Hz, fara mediere, 1.3 Ga
      memset(hist, 0, sizeof(hist));
      histIdx = 0;
      drawFooter("porneste un consumator!");
      break;
    case MODE_METEO:
      drawFooter("BOOT=mod urmator");
      break;
    default: break;
  }
}

// ---------------- Buton ----------------
void handleButton() {
  bool down = digitalRead(PIN_BTN) == LOW || digitalRead(PIN_BTN_EXT) == LOW;
  uint32_t now = millis();
  if (down && !btnWasDown) {
    btnDownAt = now;
    longFired = false;
  } else if (down && !longFired && now - btnDownAt > 1500) {
    longFired = true;
    if (mode == MODE_BUSOLA) {
      tone(PIN_BUZZER, 1500, 150);
      runCalibration();
    }
  } else if (!down && btnWasDown && !longFired && now - btnDownAt > 30) {
    mode = (Mode)((mode + 1) % NUM_MODES);
    enterMode();
    tone(PIN_BUZZER, 800 + 150 * mode, 40);  // beep de confirmare, ton per mod
  }
  btnWasDown = down;
}

// ---------------- Setup / Loop ----------------
void setup() {
  Serial.begin(115200);
  pinMode(PIN_BTN, INPUT_PULLUP);
  pinMode(PIN_BTN_EXT, INPUT_PULLUP);
  pinMode(PIN_VBUS, INPUT);
  analogSetPinAttenuation(PIN_BAT_ADC, ADC_11db);  // pana la ~2.5V la pin
  pinMode(PIN_TFT_BLK, OUTPUT);
  digitalWrite(PIN_TFT_BLK, HIGH);  // backlight pornit

  Wire.begin(PIN_SDA, PIN_SCL, 400000);
  SPI.begin(PIN_TFT_SCK, -1, PIN_TFT_MOSI, PIN_TFT_CS);

  tft.initR(TAB_VARIANT);
  tft.setRotation(0);  // portret 128x160
  tft.fillScreen(ST77XX_BLACK);

  prefs.begin("magdet", false);
  offX = prefs.getFloat("offX", 0); offY = prefs.getFloat("offY", 0); offZ = prefs.getFloat("offZ", 0);
  sclX = prefs.getFloat("sclX", 1); sclY = prefs.getFloat("sclY", 1); sclZ = prefs.getFloat("sclZ", 1);

  bmeOk = bme.begin(0x77, &Wire);

  tft.setTextSize(2);
  tft.setTextColor(ST77XX_CYAN);
  tft.setCursor(10, 60);
  tft.print("MagDetector");
  tft.setTextSize(1);
  tft.setTextColor(0x7BEF);
  tft.setCursor(24, 84);
  tft.print("Carbon S2 v1.0");
  Serial.printf("MagDetector start. BME280: %s\n", bmeOk ? "OK" : "LIPSA");
  delay(1200);

  enterMode();
}

void loop() {
  handleButton();
  uint32_t now = millis();

  // esantionare magnetometru
  if (now - tSample >= 10 && (mode == MODE_BUSOLA || mode == MODE_MAGNET || mode == MODE_CABLU)) {
    if (hmcDataReady()) {
      tSample = now;
      int16_t x, y, z;
      if (hmcRead(x, y, z)) {
        if (mode == MODE_CABLU) {
          acX[acIdx] = x * curUtPerLsb;
          acY[acIdx] = y * curUtPerLsb;
          acZ[acIdx] = z * curUtPerLsb;
          acIdx = (acIdx + 1) % AC_N;
          if (acCount < AC_N) acCount++;
        } else if (mode == MODE_BUSOLA) {
          if (!hmcSaturated(x, y, z)) {
            float mx = (x - offX) * sclX;
            float my = (y - offY) * sclY;
            float mzc = (z - offZ) * sclZ;
            if (now - tUi >= 100) { tUi = now; uiBusola(mx, my, mzc); }
          }
        } else {  // MODE_MAGNET
          if (now - tUi >= 200) {
            tUi = now;
            uiMagnet(x, y, z, hmcSaturated(x, y, z));
          }
        }
      }
    }
  }

  if (mode == MODE_CABLU && now - tUi >= 500) { tUi = now; uiCablu(); }
  if (mode == MODE_METEO && now - tUi >= 1000) { tUi = now; uiMeteo(); }
  if (now - tBat >= 5000) { tBat = now; drawBattery(); }
}

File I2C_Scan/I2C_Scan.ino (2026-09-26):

// I2C Scanner pentru GroundStudio Carbon S2 (ESP32-S2FN4R2)
// Scaneaza mai multe perechi SDA/SCL candidate si identifica chip-urile gasite.
// Proiect: MagDetector (busola + poli magnet + detector cabluri)

#include <Wire.h>

// Perechi candidate {SDA, SCL}. Evitate: 0 (boot), 19/20 (USB), 26 (PSRAM), 45/46 (strapping)
const int pinPairs[][2] = {
  {8, 9},   {9, 8},
  {1, 2},   {2, 1},
  {3, 4},   {4, 3},
  {5, 6},   {6, 5},
  {7, 10},  {10, 7},
  {11, 12}, {12, 11},
  {13, 14}, {14, 13},
  {15, 16}, {16, 15},
  {17, 18}, {18, 17},
  {21, 33}, {33, 21},
  {33, 34}, {34, 33},
  {35, 36}, {36, 35},
  {37, 38}, {38, 37},
};
const int numPairs = sizeof(pinPairs) / sizeof(pinPairs[0]);

const char* identify(uint8_t addr) {
  switch (addr) {
    case 0x0D: return "QMC5883L (magnetometru, clona)";
    case 0x1E: return "HMC5883L (magnetometru, original)";
    case 0x76: return "BMx280 (temp/presiune, SDO=GND)";
    case 0x77: return "BMx280 (temp/presiune, SDO=VCC)";
    default:   return "necunoscut";
  }
}

// Pentru BMx280 citim registrul de chip ID (0xD0) ca sa stim exact ce e
void checkBmx280(uint8_t addr) {
  Wire.beginTransmission(addr);
  Wire.write(0xD0);
  if (Wire.endTransmission(false) != 0) return;
  if (Wire.requestFrom((int)addr, 1) != 1) return;
  uint8_t id = Wire.read();
  Serial.printf("      chip ID 0x%02X -> %s\n", id,
                id == 0x60 ? "BME280 (are si umiditate!)" :
                id == 0x58 ? "BMP280 (doar temp+presiune)" :
                id == 0x61 ? "BME680" : "ID necunoscut");
}

int scanPair(int sda, int scl, bool verbose) {
  Wire.end();
  if (!Wire.begin(sda, scl, 100000)) return 0;
  Wire.setTimeOut(50);
  int found = 0;
  for (uint8_t addr = 0x08; addr <= 0x77; addr++) {
    Wire.beginTransmission(addr);
    if (Wire.endTransmission() == 0) {
      found++;
      if (verbose) {
        Serial.printf("    0x%02X - %s\n", addr, identify(addr));
        if (addr == 0x76 || addr == 0x77) checkBmx280(addr);
      }
    }
  }
  return found;
}

void setup() {
  Serial.begin(115200);
  delay(3000);  // timp pentru re-enumerare USB CDC
  Serial.println("\n=== I2C Scanner - Carbon S2 ===");
}

void loop() {
  bool anyFound = false;
  for (int i = 0; i < numPairs; i++) {
    int sda = pinPairs[i][0], scl = pinPairs[i][1];
    int n = scanPair(sda, scl, false);
    if (n > 0) {
      anyFound = true;
      Serial.printf("\n>>> GASIT pe SDA=GPIO%d SCL=GPIO%d (%d dispozitive):\n", sda, scl, n);
      scanPair(sda, scl, true);
    }
  }
  if (!anyFound)
    Serial.println("Nimic gasit. Verifica firele (VCC, GND, SDA, SCL) si reia.");
  Serial.println("\n--- rescan in 5s ---");
  delay(5000);
}
